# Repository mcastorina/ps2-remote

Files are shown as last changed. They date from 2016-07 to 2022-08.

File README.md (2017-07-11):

# ps2-remote

## What is it?
Make my Playstation 2 reset button be controlled remotely. It uses an
infrared sensor (for the remote part), and a single input MUX (for
simulating a button press).

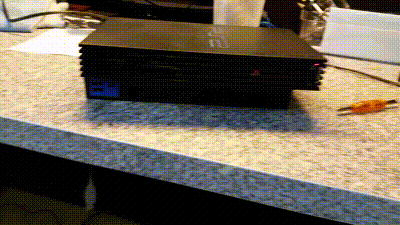
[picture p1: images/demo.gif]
PS2 Remote Demo


## Motivation
I don't want to get up to turn on and off my Playstation 2.

## Dependencies
Arduino Libraries:

* [Arduino-IRremote](https://github.com/shirriff/Arduino-IRremote)

## Status
- [x] Working prototype on breadboard
- [x] Transfer off of Arduino board
- [x] Design PCB
- [x] Order PCB
- [x] Done!

## Future Goals
This project converts any button into an IR controlled button, however
it requires soldering and electrical knowledge to do so. A future goal
is to simplify the process to allow anyone to convert the buttons.

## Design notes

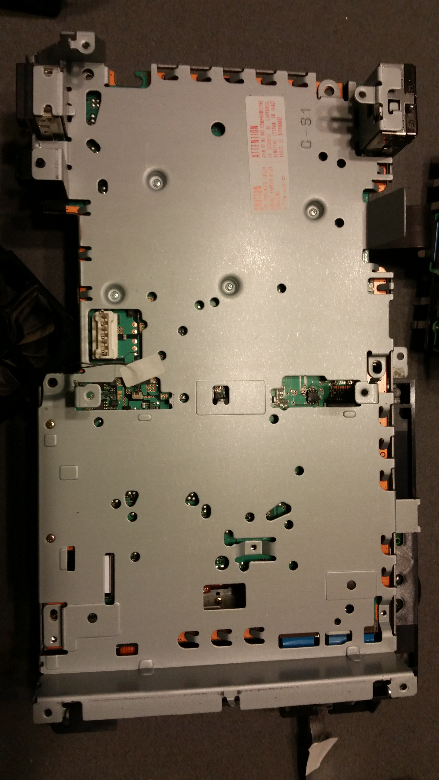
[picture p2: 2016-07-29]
images/ps2.jpg

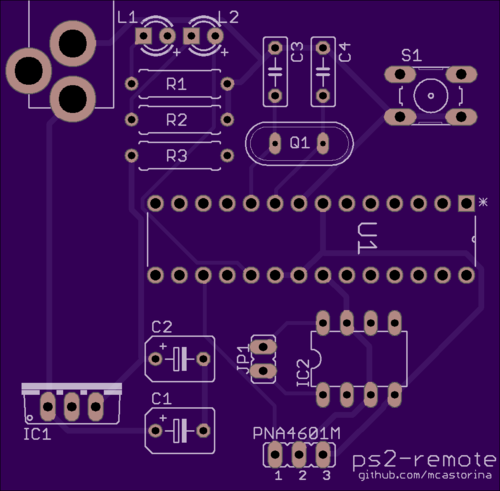
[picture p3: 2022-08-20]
images/oshpark.png

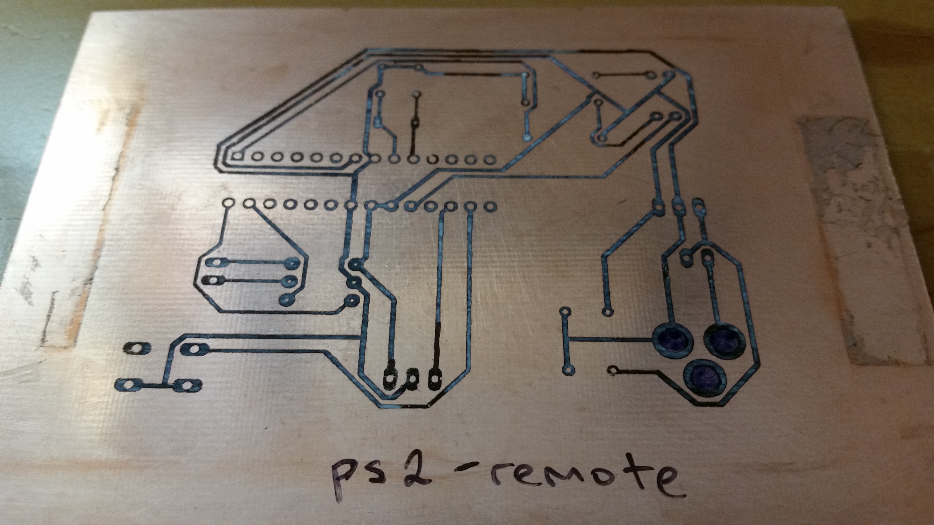
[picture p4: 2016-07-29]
images/pcb.jpg

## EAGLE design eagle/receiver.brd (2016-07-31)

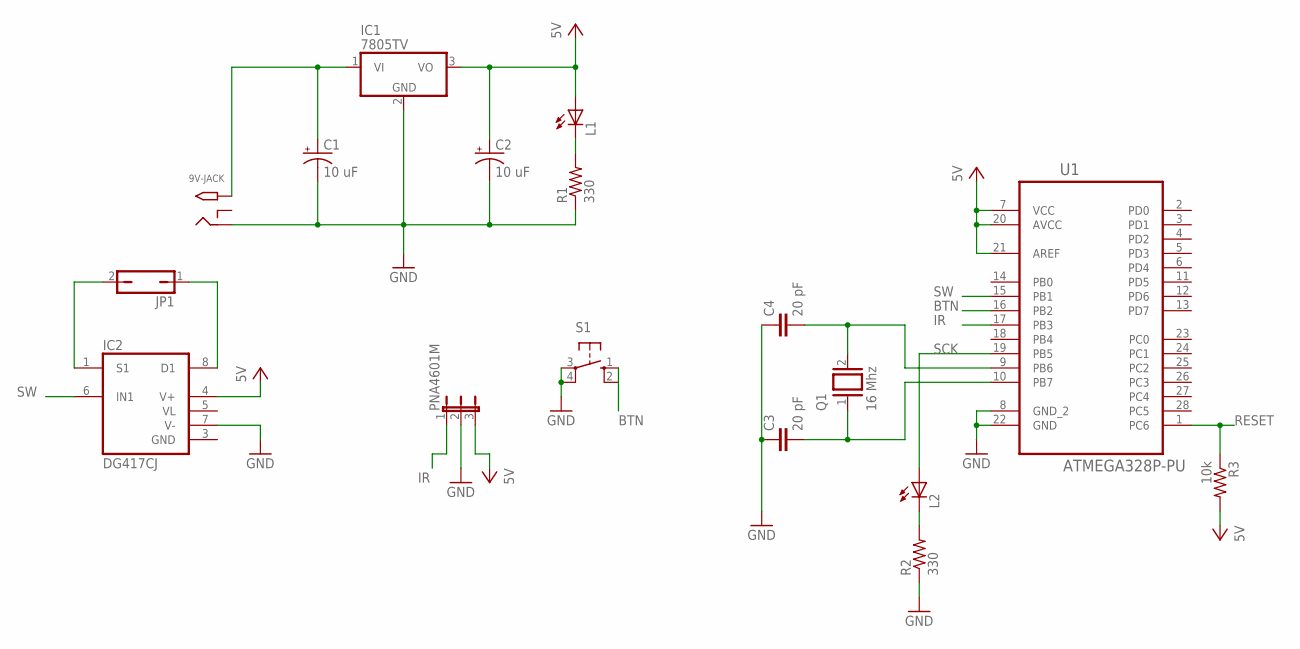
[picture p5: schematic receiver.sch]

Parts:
9V-JACK: 9V Input; PJ-102A
C1, C2: 10 uF; B45181B
C3, C4: 20 pF; C050-025X075
IC1: 7805TV; TO220V
IC2: DG417CJ; DIL08
JP1: JP1Q; JP1
L1, L2: LED3MM
PNA4601M: JP2E; JP2
Q1: 16 Mhz; QS
R1, R2: 330; RES400MIL
R3: 10k; RES400MIL
S1: B3F-1052; B3F-10XX
U1: ATMEGA328P-PU; DIP254P762X457-28

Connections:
5V: C2.+, IC1.3 (VO), IC2.4 (V+), L1.A, PNA4601M.3, R3.2, U1.7 (VCC), U1.20 (AVCC), U1.21 (AREF)
BTN: S1.1 (S), U1.16 (PB2)
GND: 9V-JACK.RING, C1.-, C2.-, C3.1, C4.1, IC1.2 (GND), IC2.3 (GND), IC2.7 (V-), PNA4601M.2, R1.1, R2.1, S1.3, S1.4 (P1), U1.8 (GND_2), U1.22 (GND)
IR: PNA4601M.1, U1.17 (PB3)
unnamed: L1.K (C), R1.2
unnamed: IC2.1 (S1), JP1.2
unnamed: C3.2, Q1.1, U1.10 (PB7)
unnamed: C4.2, Q1.2, U1.9 (PB6)
unnamed: IC2.8 (D1), JP1.1
unnamed: 9V-JACK.TIP, C1.+, IC1.1 (VI)
unnamed: L2.K (C), R2.2
RESET: R3.1, U1.1 (PC6)
SCK: L2.A, U1.19 (PB5)
SW: IC2.6 (IN1), U1.15 (PB1)
VL: IC2.5 (VL)

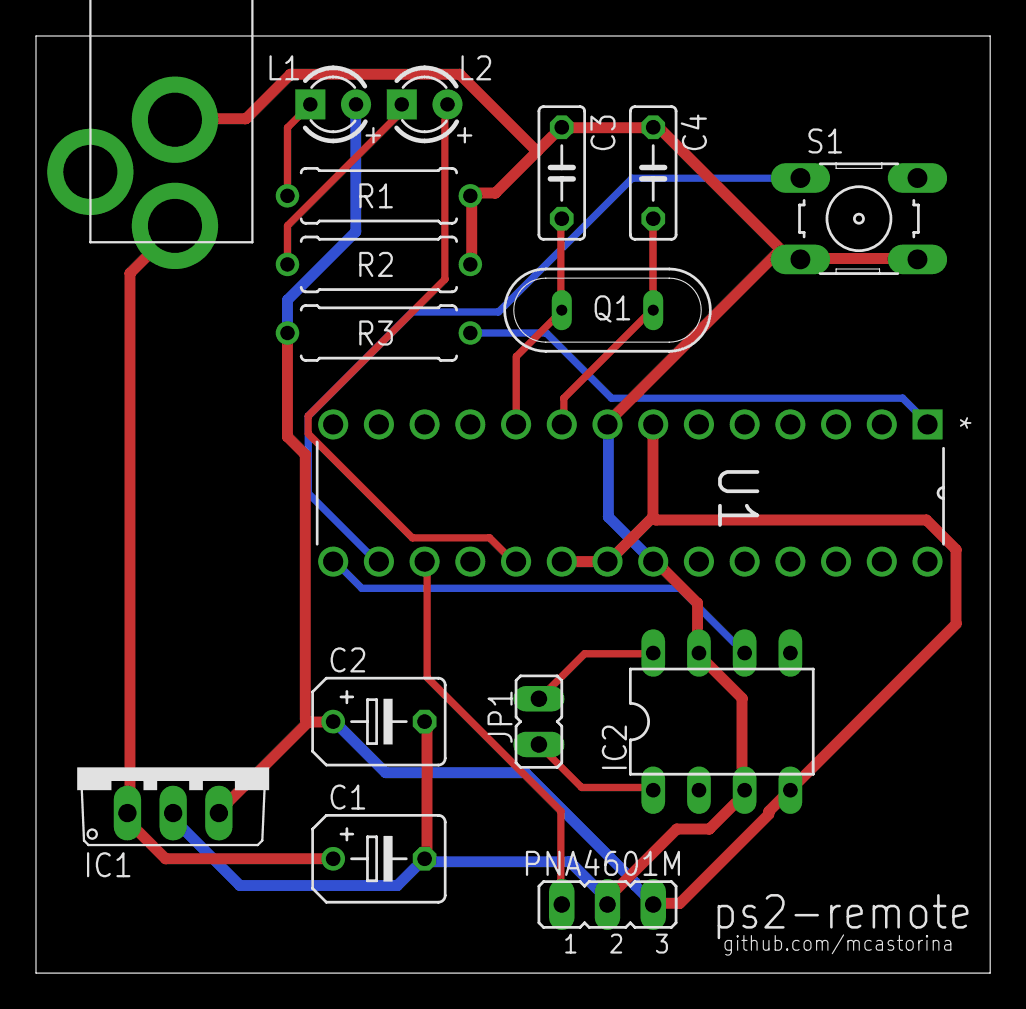
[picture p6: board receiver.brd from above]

Board: 2 copper layers, 53.0 x 52.1 mm, 17 parts (0 on the bottom side), 14 nets.

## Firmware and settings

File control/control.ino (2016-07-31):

/*
 * Remote control button.
 *
 * This project converts a physical button into a remotely controlled
 * button. It does this using an infrared (IR) receiver and a digital
 * potentiometer. The code below will wait for an IR signal (e.g. sent
 * from a television remote control) and change the resistance on the
 * potentiometer to simulate a physical button press.
 *
 * Data Flow:
 *      IR )))      Receiver ----> Button
 */
#include <EEPROM.h>
#include <IRremote.h>

// #define DEBUG
#define LED_PIN         13      // LED pin
#define RECV_PIN        11      // IR pin
#define BUTTON_PIN      10      // Button input (negative logic)
#define SWITCH_PIN      9       // Digital switch control (normally open)

void reset(void);
void power_off(void);
void blink(int count);

/* Map of IR code to function call */
static struct {
    long ir_code;
    void (*fn)(void);
} ir_map[] = {
    {0, reset},
    {0, power_off},
    {0, NULL}
};

IRrecv irrecv(RECV_PIN);
decode_results results; // IR Input

/*
 * Initialize IR receiver, I2C, and button input.
 */
void setup() {
#ifdef DEBUG
    Serial.begin(9600);
    while (!Serial);
#endif /* DEBUG */

    /* Setup IR receiver and digital switch */
    irrecv.enableIRIn();
    pinMode(SWITCH_PIN, OUTPUT);
    press_button(false);
    /* Button for recording IR code */
    pinMode(BUTTON_PIN, INPUT_PULLUP);
    /* LED for visual confirmation */
    pinMode(LED_PIN, OUTPUT);
#ifdef DEBUG
    /* Make sure the number of codes we have fits in EEPROM */
    if (sizeof(ir_map) / sizeof(ir_map[0])-1 > EEPROM.length() * sizeof(long)) {
        Serial.println("Warning: ir_map exceeds EEPROM length");
    }
#endif /* DEBUG */
    /* Set codes to value in EEPROM */
    get_values();
}

/*
 * If button was pressed, update the codes.
 * If we got an IR code, check against ir_map and call function.
 */
void loop() {
    if (!digitalRead(BUTTON_PIN))
        update_codes();
    if (irrecv.decode(&results)) {
        long code = get_code(&results);
        for (int index = 0; ir_map[index].fn != NULL; index++) {
            if (code == ir_map[index].ir_code) {
                ir_map[index].fn();
            }
        }
        delay(100);
        irrecv.resume();
    }
}

/*
 * Simulates a button press by controlling a digital potentiometer via
 * I2C.
 */
void press_button(boolean down) {
    digitalWrite(SWITCH_PIN, down);
    digitalWrite(LED_PIN, down);    // visual confirmation
#ifdef DEBUG
    Serial.print("press_button: ");
    Serial.println(down);
#endif /* DEBUG */
}

/*
 * Updates the IR code to listen for.
 */
void update_codes() {
#ifdef DEBUG
    Serial.println("updating codes");
#endif /* DEBUG */
    blink(3);                                       // Visual cue
    /* Update the ir_map */
    for (int index = 0; ir_map[index].fn != NULL; index++) {
        while (!irrecv.decode(&results));           // Wait for signal
        long val = get_code(&results);
        ir_map[index].ir_code = val;
        set_value(index, ir_map[index].ir_code);    // Store result
        delay(100);
        irrecv.resume();
        blink(1);                                   // Visual cue
#ifdef DEBUG
        Serial.print("update_code ");
        Serial.print(index);
        Serial.print(": ");
        Serial.println(val, HEX);
#endif /* DEBUG */
    }
}

/*
 * Gets the values stored in EEPROM, and populates ir_map.
 */
void get_values() {
    for (int index = 0; ir_map[index].fn != NULL; index++) {
        long val = 0;
        for (int i = 0; i < sizeof(long) &&
                        i + index * sizeof(long) < EEPROM.length(); ++i) {
            int offset = (i << 3);
            byte n = EEPROM.read(i + index * sizeof(long));
            val |= ((long)n << offset);
        }
        ir_map[index].ir_code = val;
#ifdef DEBUG
        Serial.print("get_value: ");
        Serial.print(index);
        Serial.print(", ");
        Serial.println(val, HEX);
#endif /* DEBUG */
    }
}

/*
 * Sets the value stored in EEPROM.
 */
void set_value(int index, long val) {
    for (int i = 0; i < sizeof(long) &&
                    i + index * sizeof(long) < EEPROM.length(); ++i) {
        int offset = (i << 3);
        byte n = (val & (0xffL << offset)) >> offset;
        EEPROM.write(i + index * sizeof(long), n);
    }
#ifdef DEBUG
    Serial.print("set_value: ");
    Serial.println(val, HEX);
#endif /* DEBUG */
}

/*
 * Records the code from the IR receiver.
 */
long get_code(decode_results *ptr) {
    long val = ptr->value;
#ifdef DEBUG
    Serial.print("get_code: ");
    Serial.println(val, HEX);
#endif /* DEBUG */
    return val;
}

/*
 * Blink LED_PIN count times.
 */
void blink(int count) {
    for (int i = 0; i < count; i++) {
        digitalWrite(LED_PIN, HIGH);
        delay(100);
        digitalWrite(LED_PIN, LOW);
        delay(100);
    }
}

/*
 * PS2 reset is a quick press.
 */
void reset(void) {
    press_button(true);
    delay(100);
    press_button(false);
}

/*
 * PS2 power off is a press and hold.
 */
void power_off(void) {
    press_button(true);
    delay(2500);
    press_button(false);
}

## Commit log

2016-07-09 Added debug code, fixed EEPROM storing, and fixed compile error
    Fully tested and works on a breadboard.
    [control.ino]
2016-07-09 Simplified get_code
    Instead of using the raw data to generate a code, I changed to using the
    provided 'value' attribute. This is a more unique identifier and less
    prone to error.
    [control.ino]
2016-07-09 Fixed EEPROM reading and writing the full long value
    Previously, I was only storing half the long. I fixed this by
    typecasting to long values instead of ints.
    [control.ino]
2016-07-09 Updated to allow multiple buttons
    Each button now has a map to a function, and multiple IR codes can be
    saved.
2016-07-11 Transferred off of Arduino board
2016-07-13 Initial commit of eagle files
    [receiver.brd, receiver.sch]
2016-07-13 Finished design of PCB
2016-07-24 Added LED output for visual confirmation
2016-07-25 Fixed reversed DC power jack and finished PCB
    [receiver.brd, receiver.sch]
2016-07-29 Initialized button as unpressed in setup
2016-07-31 Removed dpot from project and replaced with single input MUX
    [receiver.brd, receiver.sch]
2016-07-31 Updated README to reflect current status
2016-09-05 Installed OSHPark board and finished!
2022-08-20 Add oshpark board image
